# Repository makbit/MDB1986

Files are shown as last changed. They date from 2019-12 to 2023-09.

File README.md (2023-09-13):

## MDB1986 - Milandr Development Board for [K1986BE1QI MCU (package LQFP-144)](https://ic.milandr.ru/products/mikrokontrollery_i_protsessory/32_razryadnye_mikrokontrollery/1986vekh_avia/k1986ve1t/).
> This is an open source hardware project for tutorial purposes.







The PCB was designed in the Eagle CAD 9.0.

The [`Blink103`](Blink103) folder contains firmware for on-board debugger MCU (STM32F103). It can be used to test debugger curcuit and target MCU with JTAG IDCODE instruction. Project files were created with the [Keil uVision MDK](https://www.keil.com/demo/eval/arm.htm). The board schematics can be found in [`MDB1986-Schema.png`](MDB1986-Schema.png) file.

### MDB198 Development Board :cool:
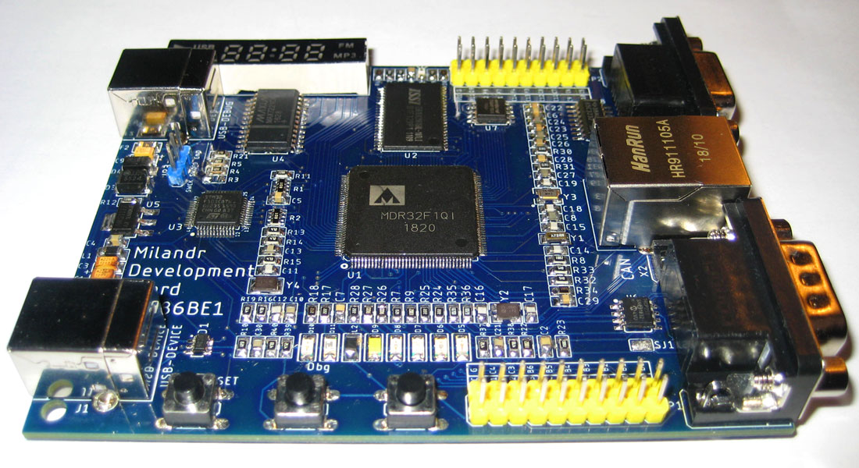
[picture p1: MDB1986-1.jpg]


## TODO :pen:
- [x] Solder the board :+1:
- [x] Download debugger firmware
- [x] Install [MDR Library Pack](https://ic.milandr.ru/soft/)
- [ ] Build and run Demo test
- [ ] Publish articles!

[GitHub readme tips&tricks](https://help.github.com/articles/basic-writing-and-formatting-syntax/)

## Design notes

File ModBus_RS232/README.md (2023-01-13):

## ModBus_RS232 - FreeModBus RTU Slave demonstration firmware for Milandr 1986BE1T (QI) board.
> Platform: Milandr MCU K1986BE1QI.

The source code is based on the [freemodbus library](https://github.com/cwalter-at/freemodbus) by Christian Walter.

### Important note: Add call to "xMBRTUTransmitFSM ();" in mbrtu.c file, Line 215.

This Demo firmware runs at 80MHz and uses UART#2 (Port_D 13, Port_D 14) and Timer #1 with prescaler set to 8.
UART is configured to 115200 baudrate, parity none, 2 stop bits (as recommended by the Standard).
When a button (#1 or #2) is pressed its status is written to the Coils register ucRegCoilsBuf[0], bits 4 and 5.
Color leds can be turned on and off by setting Coils register bits: 0 - blue, 1 - green, 2 - red, 3 - yellow.
Holding registers simply store predefined values: { 0, 1, 2, 3, 4, 5, 6, 7 }.

### Slave address is set to 0x0A (10 decimal).
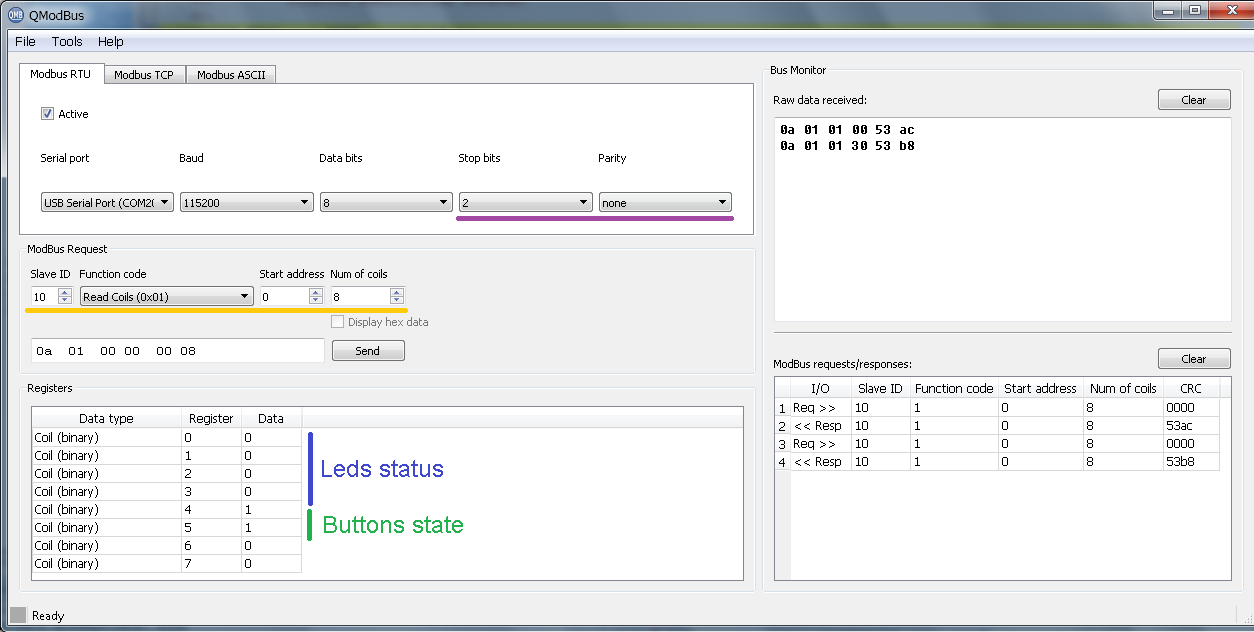
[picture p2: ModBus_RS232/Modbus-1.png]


### Timings
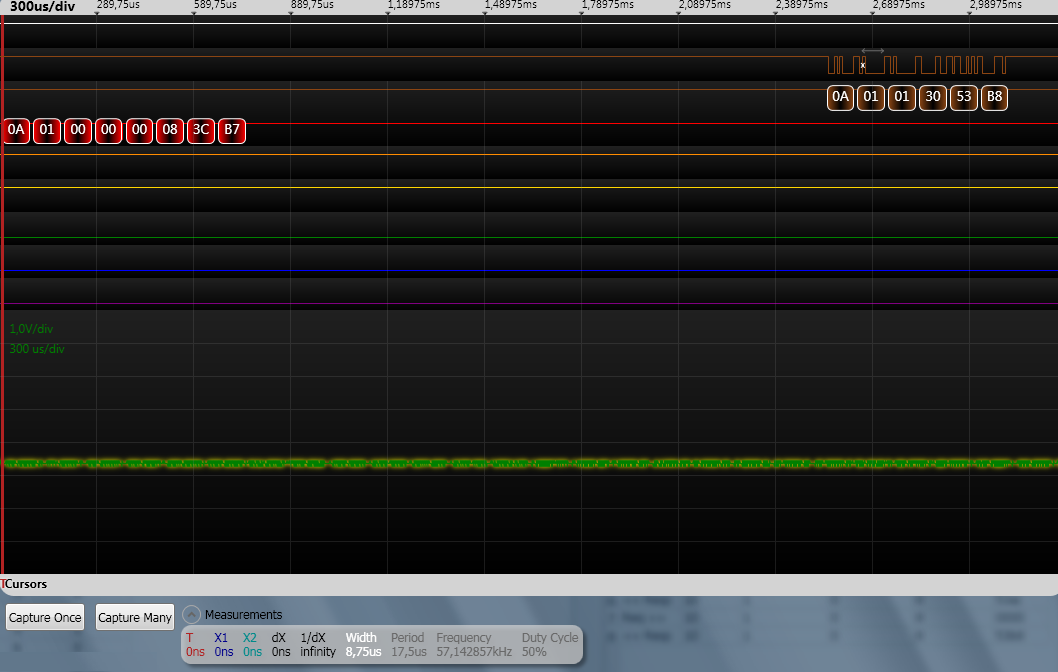
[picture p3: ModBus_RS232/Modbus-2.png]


### Project structure
The project folder contains **modbus** subfolder and the MCU specific **port_1986BE1T**.
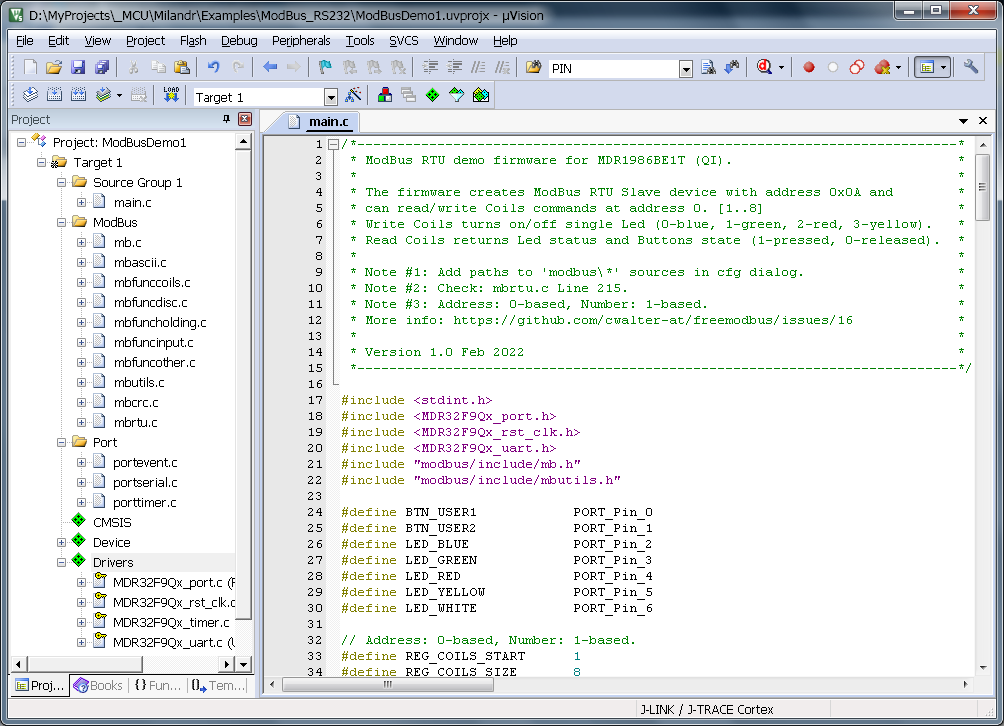
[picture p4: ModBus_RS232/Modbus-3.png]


##### Good luck! 😏

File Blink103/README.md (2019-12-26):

### Blink103 - is a simple firmware for on-board ST-Link debugger for **MDB1986 development board** based on STM32F103 or CS32F103 MCU.
It sends JTAG IDCODE sequence to the main MCU (MDR1986VE1T) and reads the reply. When the reply is a valid Cortex-M IDCODE it flashes the led.

[The Keil uVision 5 IDE](https://keil.com) was used to create and debug this project.
[The SPL (Standard Peripheral Library)](https://www.st.com/en/embedded-software/stsw-stm32054.html) 3.5.0 is required to build this project.
>Connection schematics is similar to any ST-Link clone and can be found in top folder.

### JTAG IDCODE reply on oscilloscope 
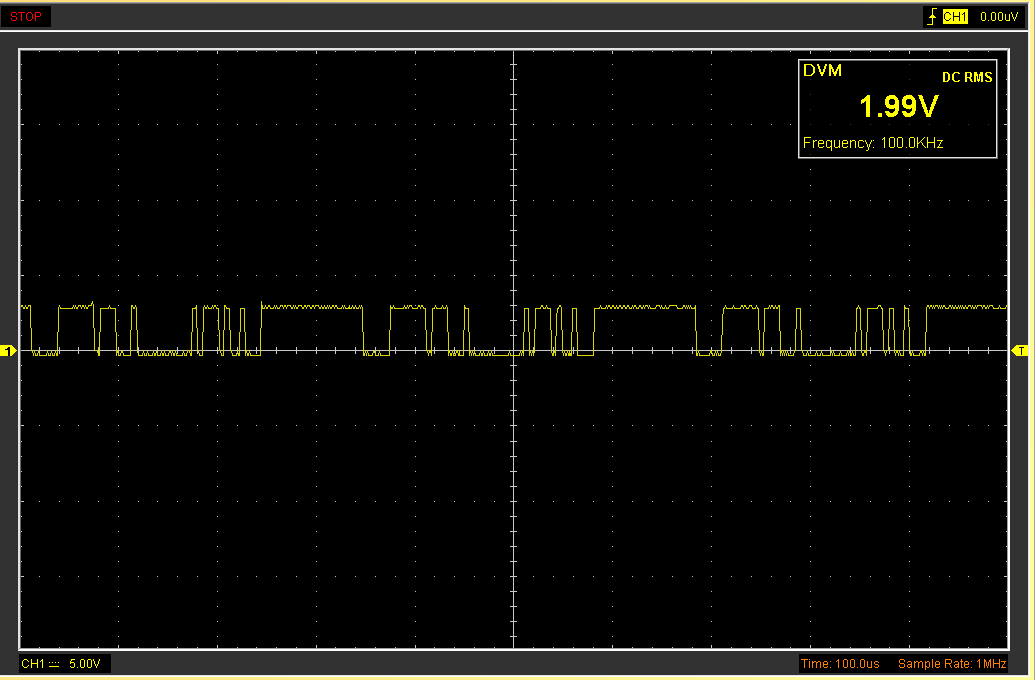
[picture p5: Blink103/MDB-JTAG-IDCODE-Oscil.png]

### Debug session in Keil uVision IDE
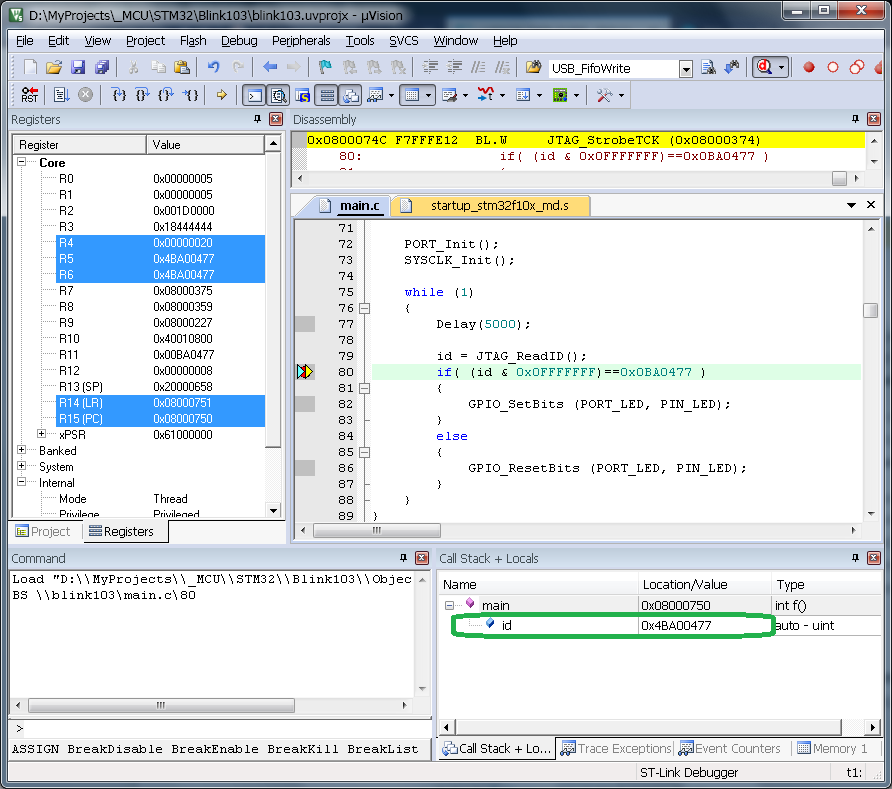
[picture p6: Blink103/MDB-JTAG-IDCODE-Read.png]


:smile:

[GitHub readme tips&tricks](https://help.github.com/articles/basic-writing-and-formatting-syntax/)

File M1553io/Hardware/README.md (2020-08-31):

# M1553io - MIL_STD_1553 input/output shield for MDB1986 Development Board.

This is a simple adapter for connecting the MDB1986 board to the MIL_STD_1553 bus.
It is based on the 5559UH13YA transciever chip by NPO "Physica". This component and transformer can be found in the 5559.lbr file.

##### The adapter board:
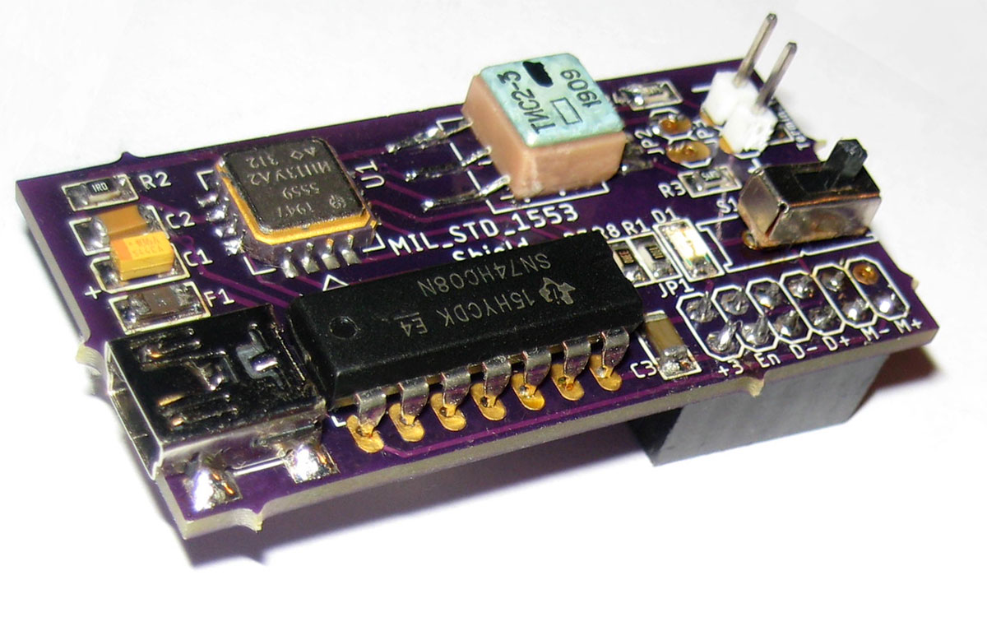
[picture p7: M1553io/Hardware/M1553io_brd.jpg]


##### The adapter schematics:
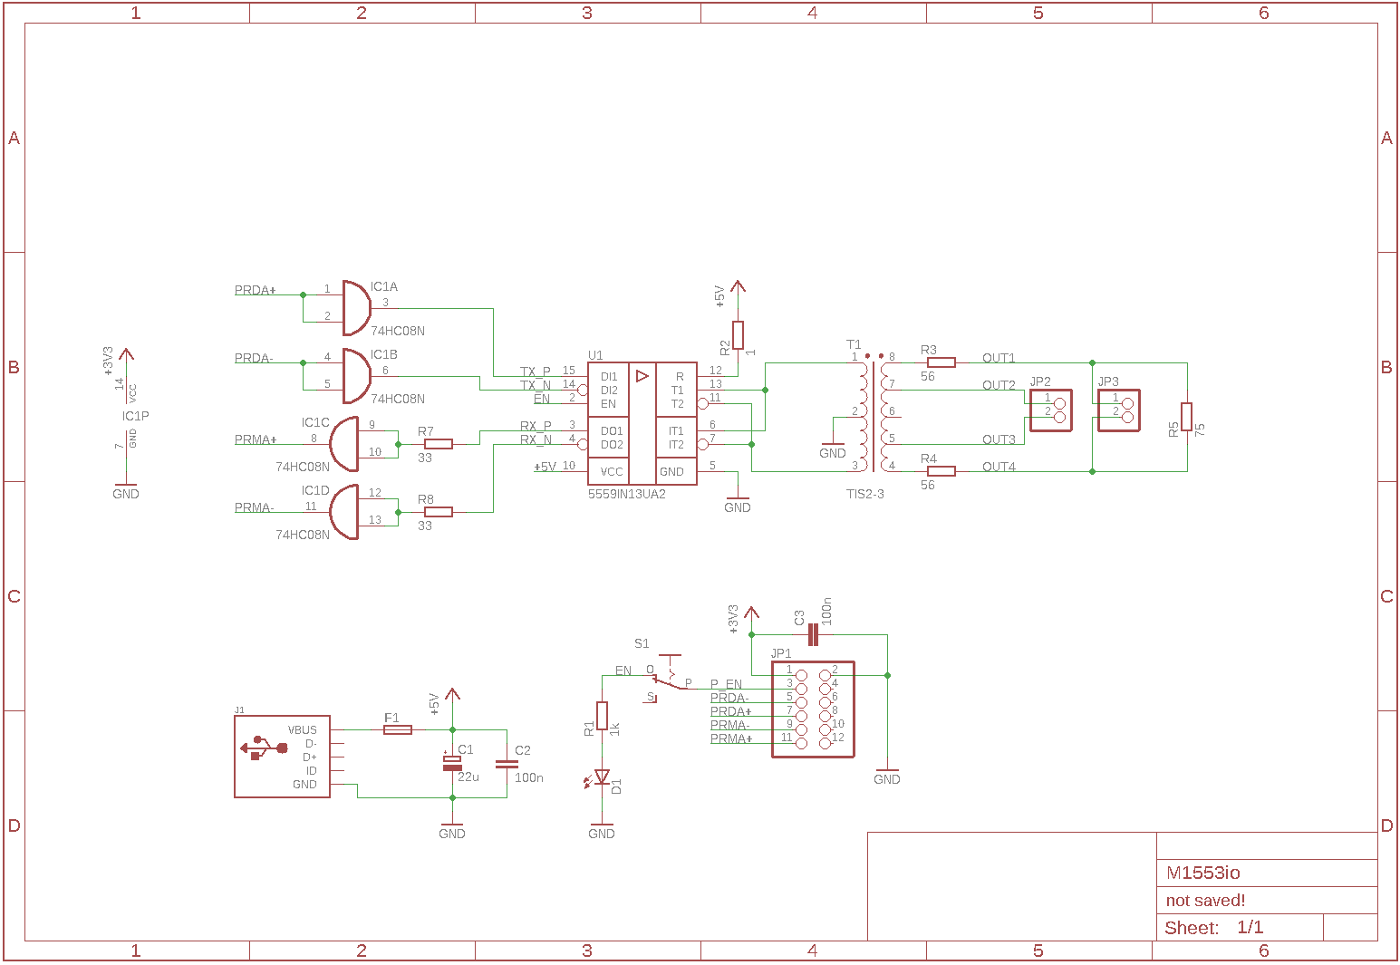
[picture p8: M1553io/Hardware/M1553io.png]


### TODO :pen:
- [ ] Use small package for 74xxx ICC as a level-shifter;
- [ ] P_EN pin should be pulled-down (or up);
- [ ] Check the length of the transformer pins;
- [ ] Add check-points (pin) for Logic-Analyzer;
- [ ] Place all components on the new Development Board;

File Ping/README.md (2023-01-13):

## Ping - ethernet example to test that hardware is functional.
> Platform: Milandr MCU K1986BE1QI.

The source code is based on the SPL example from Milandr software pack.

### Windows ping utility output.
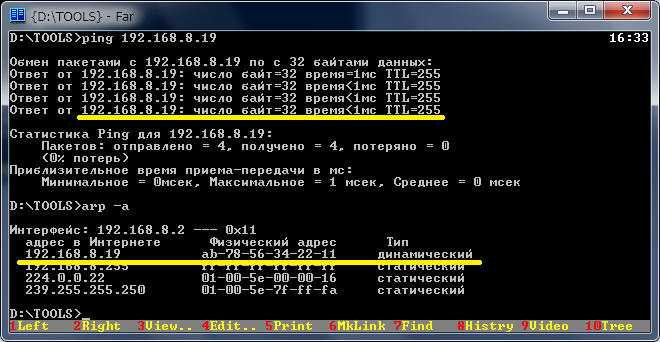
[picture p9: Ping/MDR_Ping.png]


##### Good luck!

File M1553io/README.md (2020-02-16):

## M1553 - MIL_STD_1553 simple input/output demonstration firmware for my MDB1986 board.
> Platform: Milandr MCU K1986BE1QI.

C-style source code (temporary).

### Manchester code of the test I/O sequence on a low-cost Saleae Logic analyzer.
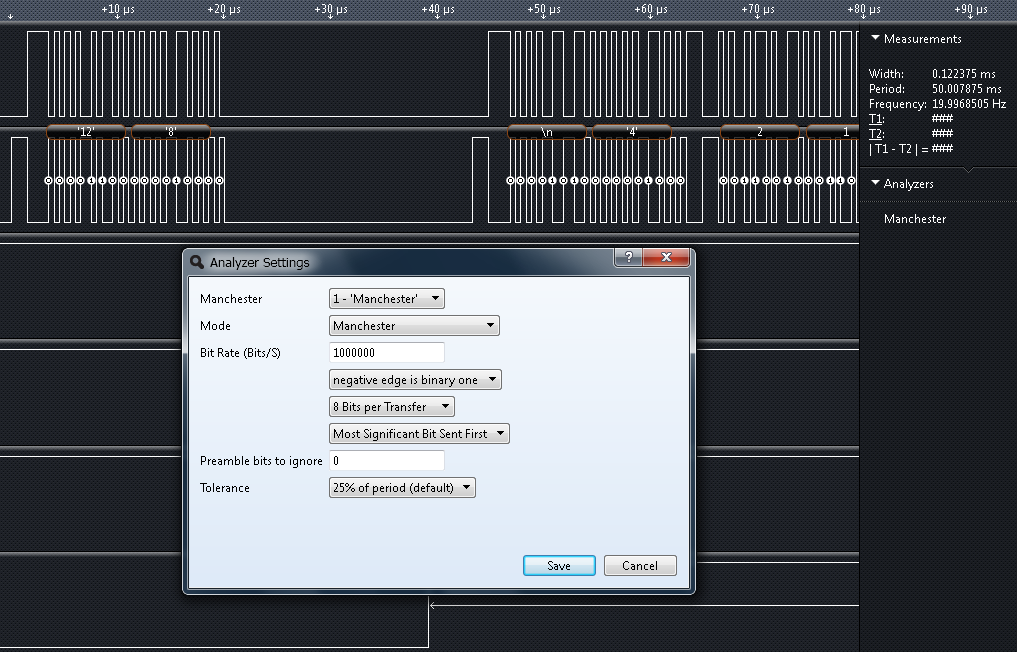
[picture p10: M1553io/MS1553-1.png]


## TODO :pen:
- [x] Logic Analyzer setup & configure
- [x] BC init :+1:
- [x] Flood test sequence
- [ ] Check for status & errors
- [ ] RT init
- [ ] IRQ handler
- [ ] Add required commands
- [ ] Reply StatusWord
- [ ] Send/Recv Vector word
- [ ] Transfer echo/test data
- [ ] Transfer any data
- [ ] Publish articles!

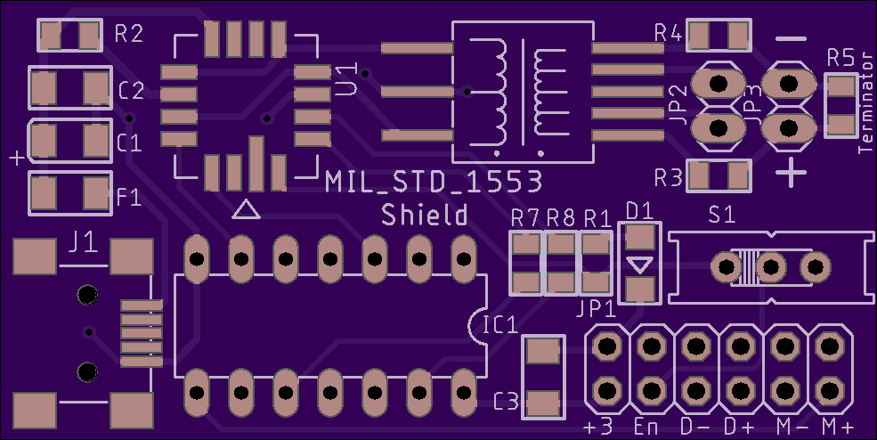
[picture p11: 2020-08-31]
M1553io/Hardware/MS1553Shield-top.png

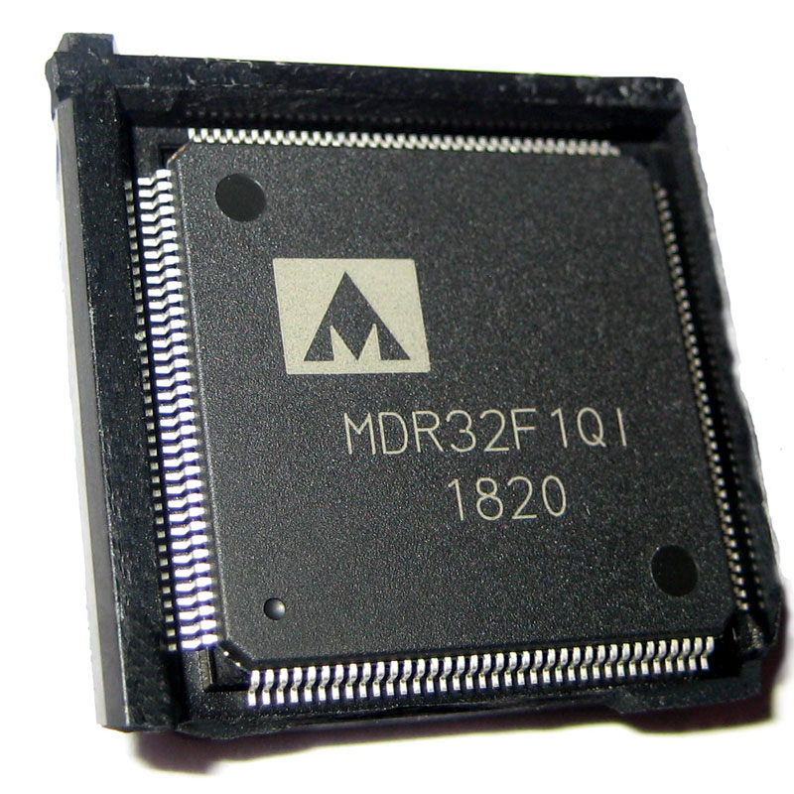
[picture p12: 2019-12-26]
MDR1986-MCU.jpg

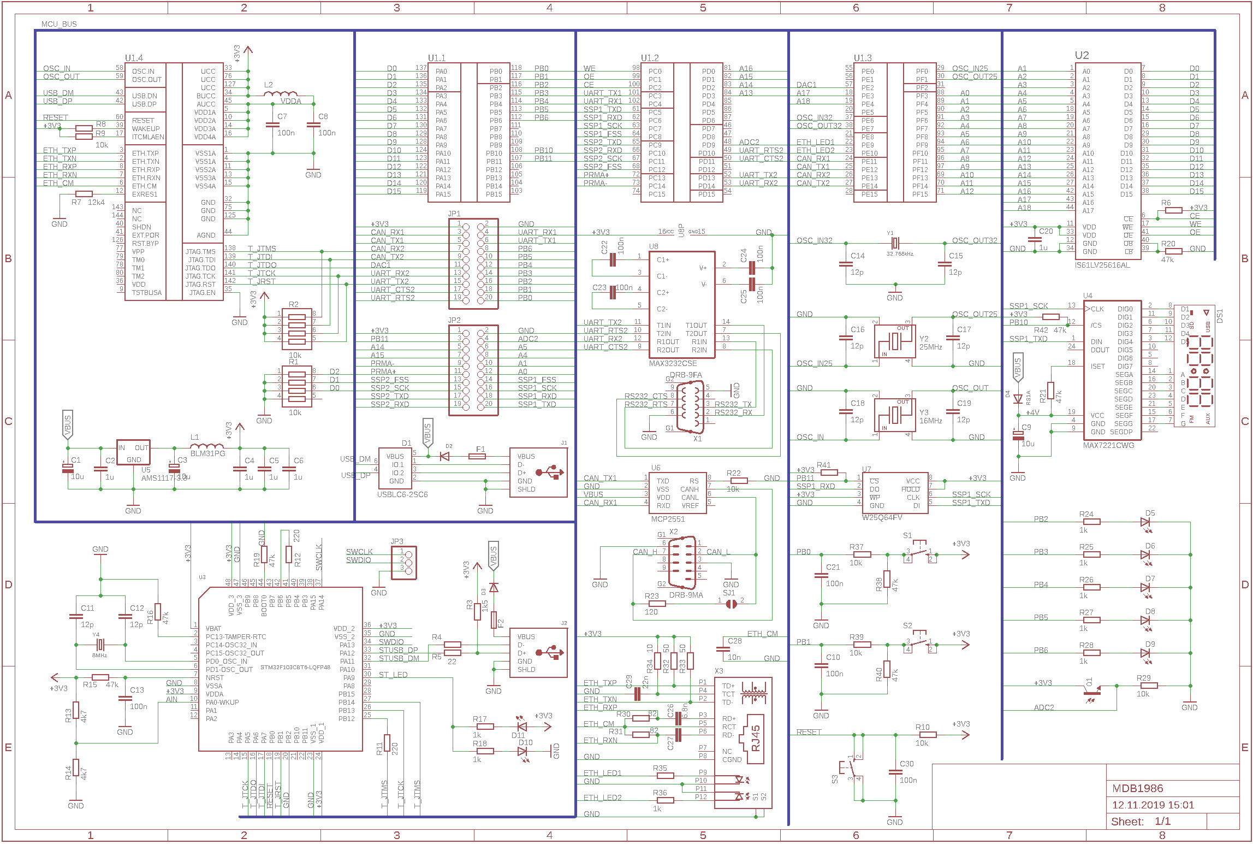
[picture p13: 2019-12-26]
MDB1986-Schema.png

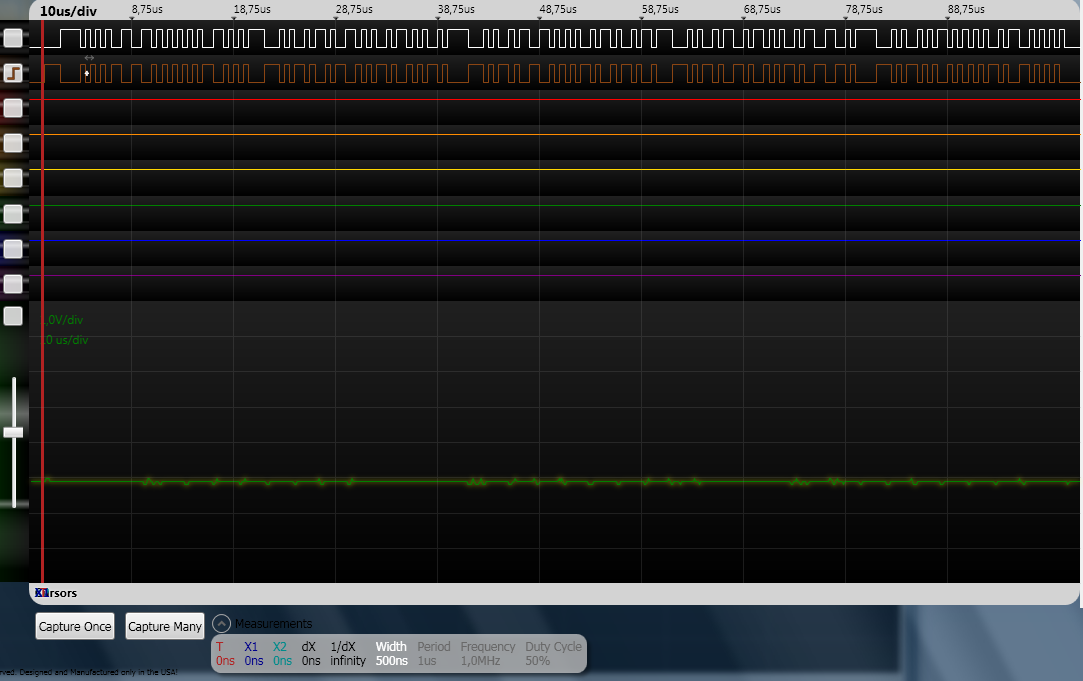
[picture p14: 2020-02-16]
M1553io/MS1553-0.png

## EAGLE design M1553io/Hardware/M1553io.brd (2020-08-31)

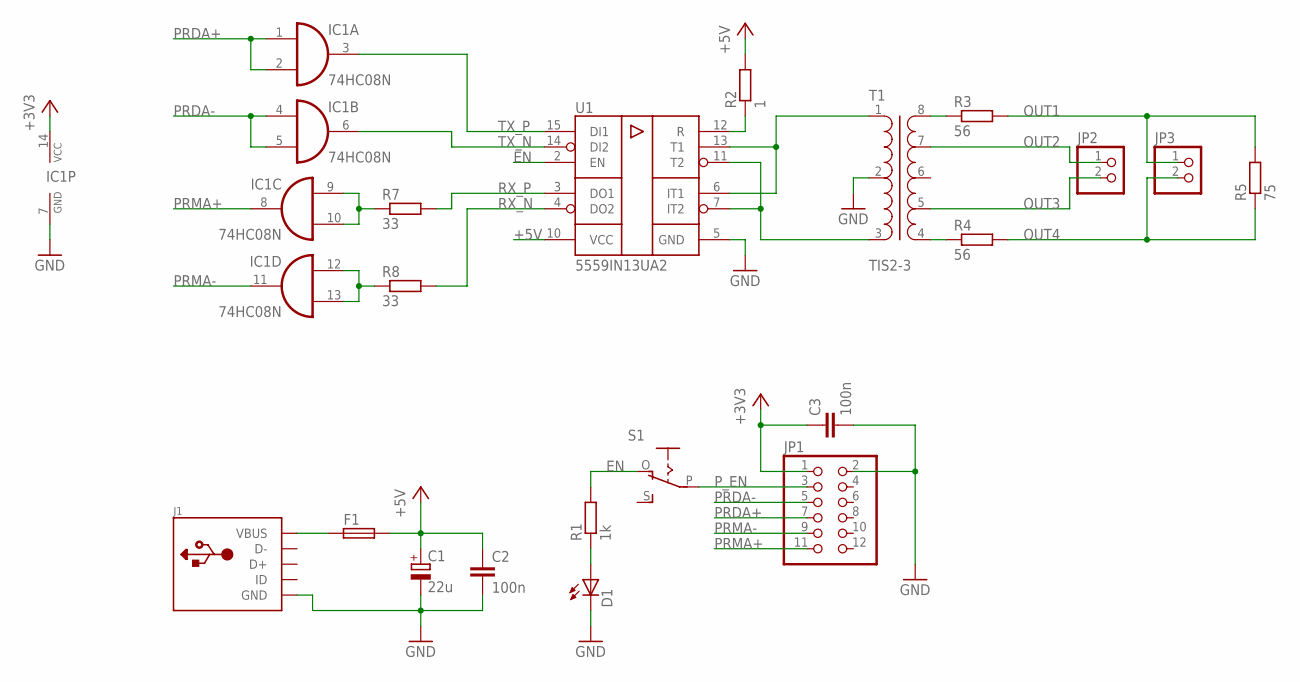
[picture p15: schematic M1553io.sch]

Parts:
C1: 22u; RCL-1206F-POL
C2, C3: 100n; RCL-1206F
D1: LED1206; LED-1206F
F1: FUSE-NSMF; RCL-1206F
IC1: 74HC08N; DIL14
J1: USB-MINI; USB-MINIB
JP1: PINHD-2X6; 2X06
JP2, JP3: PINHD-1X2; 1X02
R1: 1k; RCL-0805F
R2: 1; RCL-0805F
R3, R4: 56; RCL-0805F
R5: 75; RCL-0805F
R7, R8: 33; RCL-0805F
S1: EG1218S; EG1218
T1: TIS2-3
U1: 5559IN13UA2; 5119.16-A

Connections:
+3V3: C3.1, IC1.14 (VCC), JP1.1
+5V: C1.+, C2.1, F1.2, R2.2, U1.10 (VCC)
EN: R1.2, S1.O, U1.2 (EN)
GND: C1.-, C2.2, C3.2, D1.C, IC1.7 (GND), J1.GND, JP1.2, T1.2, U1.5 (GND)
unnamed: R3.1, T1.8
unnamed: R4.1, T1.4
unnamed: R2.1, U1.12 (R)
unnamed: F1.1, J1.VBUS
unnamed: D1.A, R1.1
unnamed: IC1.9 (I0), IC1.10 (I1), R7.1
unnamed: IC1.12 (I0), IC1.13 (I1), R8.1
OUT1: JP3.1, R3.2, R5.2
OUT2: JP2.1, T1.7
OUT3: JP2.2, T1.5
OUT4: JP3.2, R4.2, R5.1
PRDA+: IC1.1 (I0), IC1.2 (I1), JP1.7
PRDA-: IC1.4 (I0), IC1.5 (I1), JP1.5
PRMA+: IC1.8 (O), JP1.11
PRMA-: IC1.11 (O), JP1.9
P_EN: JP1.3, S1.P
RX_N: R8.2, U1.4 (DO2)
RX_P: R7.2, U1.3 (DO1)
T1: T1.1, U1.6 (IT1), U1.13 (T1)
T2: T1.3, U1.7 (IT2), U1.11 (T2)
TX_N: IC1.6 (O), U1.14 (DI2)
TX_P: IC1.3 (O), U1.15 (DI1)

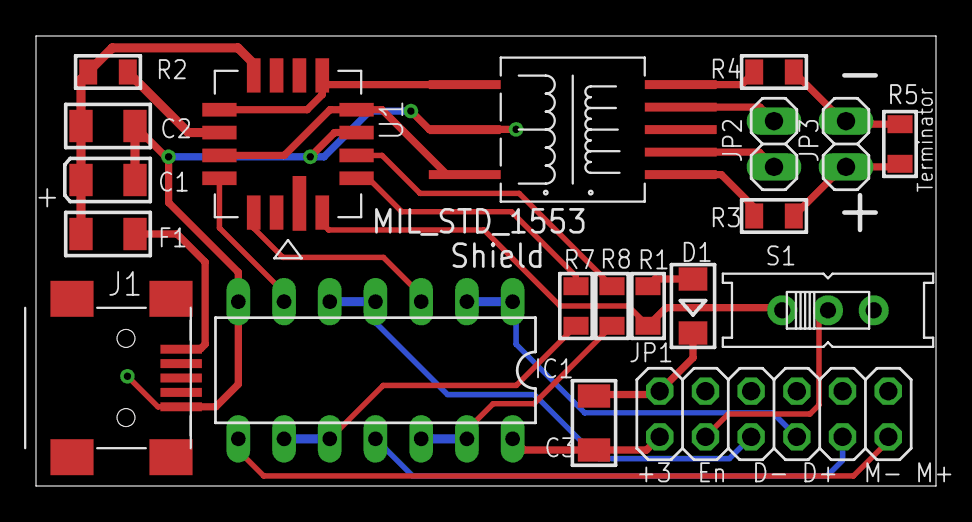
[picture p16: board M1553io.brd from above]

Board: 2 copper layers, 50.0 x 25.0 mm, 20 parts (0 on the bottom side), 26 nets.

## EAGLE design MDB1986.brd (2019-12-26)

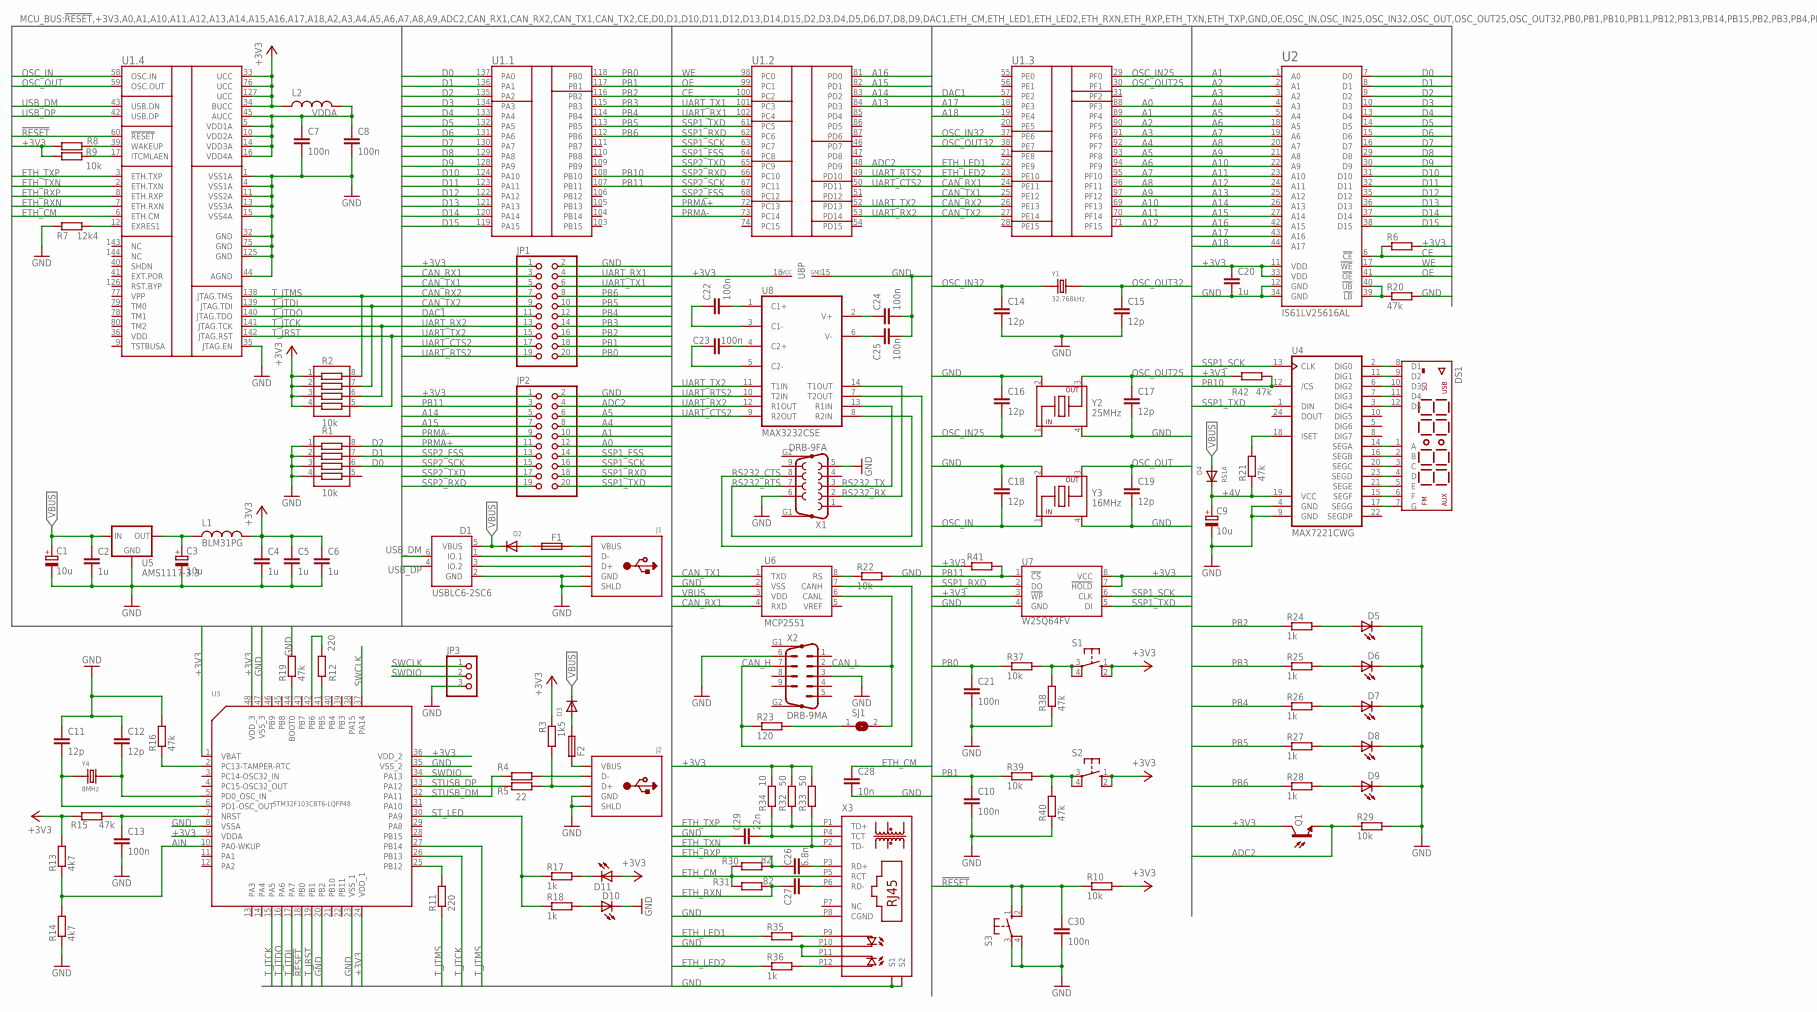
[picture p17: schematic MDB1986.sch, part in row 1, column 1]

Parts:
C1, C3, C9: 10u; RCL-1206F-POL
C2, C4, C5, C6, C20: 1u; RCL-0805F
C7, C8, C10, C13, C21, C22, C23, C24, C25, C30: 100n; RCL-0805F
C11, C12, C14, C15, C16, C17, C18, C19: 12p; RCL-0805F
C26: 6.8n; RCL-0805F
C27: C-EU0805; RCL-0805F
C28: 10n; RCL-0805F
C29: 22n; RCL-0805F
D1: USBLC6-2SC6; SOT-23-6L
D2, D3: DIODEDO-214(SMB); DO-214AA(SMB)
D4: RS1A; DO-214AC(SMA)
D5, D6, D7, D8, D9, D10, D11: LED1206; LED-1206F
DS1: LED-7SEG-12PIN-CC; LED-7SEG-12P2.54
F1, F2: FUSE-NSMF; RCL-1206F
J1, J2: USB-TYPE-B; USB-TYPE-B-4P
JP1, JP2: PINHD-2X10; 2X10
JP3: PINHD-1X3; 1X03
L1: BLM31PG; RCL-1206F
L2: L-EU1206; RCL-1206F
Q1: PHOTOTRANSISTORPT17-21C-L41-TR8; PT17-21C-L41-TR8
R1, R2: 10k; RA-1206-X4
R3: 1k5; RCL-0805F
R4, R6, R8, R35, R41: R-EU0805; RCL-0805F
R5: 22; RCL-0805F
R7: 12k4; RCL-0805F
R9, R10, R22, R29, R37, R39: 10k; RCL-0805F
R11, R12: 220; RCL-0805F
R13, R14: 4k7; RCL-0805F
R15, R16, R19, R20, R21, R38, R40, R42: 47k; RCL-0805F
R17, R18, R24, R25, R26, R27, R28, R36: 1k; RCL-0805F
R23: 120; RCL-0805F
R30, R31: 82; RCL-0805F
R32, R33: 50; RCL-0805F
R34: 10; RCL-0805F
S1, S2, S3: SWITCH-10-XX; BUTTON-B3F-10XX
SJ1: SJ
U1: MCU-K1986BE1QI; LQFP144-0.5-20X20M
U2: IS61LV25616AL; TSOP2-44-400BF
U3: STM32F103CBT6-LQFP48; LQFP48-0.5-7X7MM
U4: MAX7221CWG; SO24W
U5: AMS1117-3.3; SOT223
U6: MCP2551; SO08
U7: W25Q64FV; SOIC-8
U8: MAX3232CSE; SO16
X1: DRB-9FA; F09HP
X2: DRB-9MA; M09HP
X3: HR911105A; RJ45
Y1: 32.768kHz; XTAL-FC-135
Y2: 25MHz; XTAL-FA-238
Y3: 16MHz; XTAL-FA-238
Y4: 8MHz; XTAL-NX3225

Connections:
!RESET: C30.1, R10.1, S3.1 (S), S3.2 (S1), U1.60 (!RESET), U3.18 (PB0)
+3V3: C4.1, C5.1, C6.1, C20.1, D11.A, JP1.1, JP2.1, L1.2, L2.1, Q1.C, R2.1 (P.1), R2.2 (P.2), R2.3 (P.3), R2.4 (P.4), R3.1, R6.2, R8.1, R9.1, R10.2, R13.2, R15.1, R32.2, R33.2, R34.2, R41.1, R42.1, S1.1 (S), S1.2 (S1), S2.1 (S), S2.2 (S1), U1.33 (UCC), U1.34 (BUCC), U1.76 (UCC), U1.127 (UCC), U2.11 (VDD), U2.33 (VDD), U3.1 (VBAT), U3.9 (VDDA), U3.24 (VDD_1), U3.36 (VDD_2), U3.48 (VDD_3), U7.3 (!WP), U7.7 (!HOLD), U7.8 (VCC), U8.16 (VCC)
+4V: C9.+, D4.C, R21.1, U4.19 (VCC)
A0: JP2.12, U1.88 (PF3)
A1: JP2.10, U1.89 (PF4), U2.1 (A0)
A2: U1.90 (PF5), U2.2 (A1)
A3: U1.91 (PF6), U2.3 (A2)
A4: JP2.8, U1.92 (PF7), U2.4 (A3)
A5: JP2.6, U1.93 (PF8), U2.5 (A4)
A6: U1.94 (PF9), U2.18 (A5)
A7: U1.95 (PF10), U2.19 (A6)
A8: U1.96 (PF11), U2.20 (A7)
A9: U1.97 (PF12), U2.21 (A8)
A10: U1.69 (PF13), U2.22 (A9)
A11: U1.70 (PF14), U2.23 (A10)
A12: U1.71 (PF15), U2.24 (A11)
A13: U1.84 (PD3), U2.25 (A12)
A14: JP2.5, U1.83 (PD2), U2.26 (A13)
A15: JP2.7, U1.82 (PD1), U2.27 (A14)
A16: U1.81 (PD0), U2.42 (A15)
A17: U1.18 (PE3), U2.43 (A16)
A18: U1.19 (PE4), U2.44 (A17)
ADC2: JP2.4, Q1.E, R29.1, U1.48 (PD9)
AIN: R13.1, R14.2, U3.10 (PA0-WKUP)
BOOT0: R19.1, U3.44 (BOOT0)
CAN_H: R23.1, U6.7 (CANH), X2.7
CAN_L: SJ1.2, U6.6 (CANL), X2.2
CAN_RX1: JP1.3, U1.24 (PE11), U6.4 (RXD)
CAN_RX2: JP1.7, U1.26 (PE13)
CAN_TX1: JP1.5, U1.25 (PE12), U6.1 (TXD)
CAN_TX2: JP1.9, U1.27 (PE14)
CE: R6.1, U1.100 (PC2), U2.6 (!CE)
D0: R1.6 (P.6), U1.137 (PA0), U2.7 (D0)
D1: R1.7 (P.7), U1.136 (PA1), U2.8 (D1)
D2: R1.8 (P.8), U1.135 (PA2), U2.9 (D2)
D3: U1.134 (PA3), U2.10 (D3)
D4: U1.133 (PA4), U2.13 (D4)
D5: U1.132 (PA5), U2.14 (D5)
D6: U1.131 (PA6), U2.15 (D6)
D7: U1.130 (PA7), U2.16 (D7)
D8: U1.129 (PA8), U2.29 (D8)
D9: U1.128 (PA9), U2.30 (D9)
D10: U1.124 (PA10), U2.31 (D10)
D11: U1.123 (PA11), U2.32 (D11)
D12: U1.122 (PA12), U2.35 (D12)
D13: U1.121 (PA13), U2.36 (D13)
D14: U1.120 (PA14), U2.37 (D14)
D15: U1.119 (PA15), U2.38 (D15)
DAC1: JP1.11, U1.57 (PE2)
ETH_CM: C28.1, R30.1, R31.1, U1.6 (ETH.CM), X3.P5 (RCT)
ETH_LED1: R35.1, U1.22 (PE9)
ETH_LED2: R36.1, U1.23 (PE10)
ETH_RXN: C27.1, R31.2, U1.7 (ETH.RXN)
ETH_RXP: C26.1, R30.2, U1.8 (ETH.RXP)
ETH_TXN: R33.1, U1.2 (ETH.TXN), X3.P2 (TD-)
ETH_TXP: R32.1, U1.3 (ETH.TXP), X3.P1 (TD+)
GND: C1.-, C2.2, C3.-, C4.2, C5.2, C6.2, C7.2, C8.2, C9.-, C10.2, C11.1, C12.1, C13.2, C14.2, C15.2, C16.1, C17.2, C18.1, C19.2, C20.2, C21.2, C24.2, C25.2, C28.2, C29.1, C30.2, D1.2 (GND), D5.C, D6.C, D7.C, D8.C, D9.C, D10.C, J1.4_GND (GND), J1.M1 (SHLD), J1.M2 (SHLD), J2.4_GND (GND), J2.M1 (SHLD), J2.M2 (SHLD), JP1.2, JP2.2, JP3.3, R1.1 (P.1), R1.2 (P.2), R1.3 (P.3), R1.4 (P.4), R7.1, R14.1, R16.2, R19.2, R20.2, R22.2, R29.2, R38.1, R40.1, S3.3, S3.4 (P1), U1.1 (VSS1A), U1.4 (VSS1A), U1.11 (VSS2A), U1.13 (VSS3A), U1.15 (VSS4A), U1.32 (GND), U1.35 (JTAG.EN), U1.44 (AGND), U1.75 (GND), U1.125 (GND), U2.12 (GND), U2.34 (GND), U3.8 (VSSA), U3.20 (PB2), U3.23 (VSS_1), U3.35 (VSS_2), U3.47 (VSS_3), U4.4 (GND), U4.9 (GND), U5.1 (GND), U6.2 (VSS), U7.4 (GND), U8.15 (GND), X1.5, X1.6, X2.3, X2.6, X3.P8 (CGND), X3.P10 (GLED-), X3.P11 (YLED-), X3.SHIELD1 (S1), X3.SHIELD2 (S2), Y2.2, Y2.4, Y3.2, Y3.4
unnamed: DS1.8 (D1), U4.2 (DIG0)
unnamed: DS1.9 (D2), U4.11 (DIG1)
unnamed: DS1.10 (D3), U4.6 (DIG2)
unnamed: DS1.11 (D4), U4.7 (DIG3)
unnamed: DS1.12 (D5), U4.3 (DIG4)
unnamed: DS1.1 (A), U4.14 (SEGA)
unnamed: DS1.2 (B), U4.16 (SEGB)
unnamed: DS1.3 (C), U4.20 (SEGC)
unnamed: DS1.4 (D), U4.23 (SEGD)
unnamed: DS1.5 (E), U4.21 (SEGE)
unnamed: DS1.6 (F), U4.15 (SEGF)
unnamed: DS1.7 (G), U4.17 (SEGG)
unnamed: F1.1, J1.1_VBUS (VBUS)
unnamed: D2.A, F1.2
unnamed: C12.2, U3.5 (PD0_OSC_IN), Y4.2
unnamed: C11.2, U3.6 (PD1-OSC_OUT), Y4.1
unnamed: R21.2, U4.18 (ISET)
unnamed: D10.A, R18.2
unnamed: R12.1, U3.41 (PB5)
unnamed: R12.2, U3.42 (PB6)
unnamed: C3.+, L1.1, U5.2 (OUT), U5.4 (OUT)
unnamed: R11.2, U3.25 (PB12)
unnamed: D11.C, R17.2
unnamed: J2.2_DM (D-), R4.1
unnamed: J2.3_DP (D+), R3.2, R5.1
unnamed: C22.2, U8.1 (C1+)
unnamed: F2.1, J2.1_VBUS (VBUS)
unnamed: C13.1, R15.2, U3.7 (NRST)
unnamed: R8.2, U1.39 (WAKEUP)
unnamed: R9.2, U1.17 (ITCMLAEN)
unnamed: C22.1, U8.3 (C1-)
unnamed: R16.1, U3.2 (PC13-TAMPER-RTC)
unnamed: C23.2, U8.4 (C2+)
unnamed: C23.1, U8.5 (C2-)
unnamed: C25.1, U8.6 (V-)
unnamed: C24.1, U8.2 (V+)
unnamed: R20.1, U2.39 (!LB), U2.40 (!UB)
unnamed: R7.2, U1.12 (EXRES1)
unnamed: R23.2, SJ1.1
unnamed: R22.1, U6.8 (RS)
unnamed: D3.A, F2.2
unnamed: D9.A, R28.2
unnamed: D8.A, R27.2
unnamed: D7.A, R26.2
unnamed: R37.2, R38.2, S1.3, S1.4 (P1)
unnamed: D6.A, R25.2
unnamed: D5.A, R24.2
unnamed: C29.2, R34.1, X3.P4 (TCT)
unnamed: R36.2, X3.P12 (YLED+)
unnamed: R35.2, X3.P9 (GLED+)
unnamed: C27.2, X3.P6 (RD-)
unnamed: C26.2, X3.P3 (RD+)
unnamed: R39.2, R40.2, S2.3, S2.4 (P1)
OE: U1.99 (PC1), U2.41 (!OE)
OSC_IN: C18.2, U1.58 (OSC.IN), Y3.1 (X.IN)
OSC_IN25: C16.2, U1.29 (PF0), Y2.1 (X.IN)
OSC_IN32: C14.1, U1.37 (PE6), Y1.1
OSC_OUT: C19.1, U1.59 (OSC.OUT), Y3.3 (X.OUT)
OSC_OUT25: C17.1, U1.30 (PF1), Y2.3 (X.OUT)
OSC_OUT32: C15.1, U1.38 (PE7), Y1.2
PB0: C21.1, JP1.20, R37.1, U1.118 (PB0)
PB1: C10.1, JP1.18, R39.1, U1.117 (PB1)
PB2: JP1.16, R24.1, U1.116 (PB2)
PB3: JP1.14, R25.1, U1.115 (PB3)
PB4: JP1.12, R26.1, U1.114 (PB4)
PB5: JP1.10, R27.1, U1.113 (PB5)
PB6: JP1.8, R28.1, U1.112 (PB6)
PB10: R42.2, U1.108 (PB10), U4.12 (/CS)
PB11: JP2.3, R41.2, U1.107 (PB11), U7.1 (!CS)
PRMA+: JP2.11, U1.72 (PC13)
PRMA-: JP2.9, U1.73 (PC14)
RS232_CTS: U8.7 (T2OUT), X1.8
RS232_RTS: U8.8 (R2IN), X1.7
RS232_RX: U8.14 (T1OUT), X1.2
RS232_TX: U8.13 (R1IN), X1.3
SSP1_FSS: JP2.14, U1.64 (PC8)
SSP1_RXD: JP2.18, U1.62 (PC6), U7.2 (DO)
SSP1_SCK: JP2.16, U1.63 (PC7), U4.13 (CLK), U7.6 (CLK)
SSP1_TXD: JP2.20, U1.61 (PC5), U4.1 (DIN), U7.5 (DI)
SSP2_FSS: JP2.13, U1.68 (PC12)
SSP2_RXD: JP2.19, U1.66 (PC10)
SSP2_SCK: JP2.15, U1.67 (PC11)
SSP2_TXD: JP2.17, U1.65 (PC9)
STUSB_DM: R4.2, U3.32 (PA11)
STUSB_DP: R5.2, U3.33 (PA12)
ST_LED: R17.1, R18.1, U3.30 (PA9)
SWCLK: JP3.1, U3.37 (PA14)
SWDIO: JP3.2, U3.34 (PA13)
T_JRST: R2.5 (P.5), U1.142 (JTAG.RST), U3.19 (PB1)
T_JTCK: R2.6 (P.6), U1.141 (JTAG.TCK), U3.15 (PA5), U3.26 (PB13)
T_JTDI: R2.7 (P.7), U1.139 (JTAG.TDI), U3.17 (PA7)
T_JTDO: U1.140 (JTAG.TDO), U3.16 (PA6)
T_JTMS: R2.8 (P.8), R11.1, U1.138 (JTAG.TMS), U3.27 (PB14)
UART_CTS2: JP1.17, U1.50 (PD11), U8.9 (R2OUT)
UART_RTS2: JP1.19, U1.49 (PD10), U8.10 (T2IN)
UART_RX1: JP1.4, U1.102 (PC4)
UART_RX2: JP1.13, U1.53 (PD14), U8.12 (R1OUT)
UART_TX1: JP1.6, U1.101 (PC3)
UART_TX2: JP1.15, U1.52 (PD13), U8.11 (T1IN)
USB_D+: D1.3 (IO.2), J1.3_DP (D+)
USB_D-: D1.1 (IO.1), J1.2_DM (D-)
USB_DM: D1.6 (IO_1), U1.43 (USB.DN)
USB_DP: D1.4 (IO_2), U1.42 (USB.DP)
VBUS: C1.+, C2.1, D1.5 (VBUS), D2.C, D3.C, D4.A, U5.3 (IN), U6.3 (VDD)
VDDA: C7.1, C8.1, L2.2, U1.5 (VDD1A), U1.10 (VDD2A), U1.14 (VDD3A), U1.16 (VDD4A), U1.45 (AUCC)
WE: U1.98 (PC0), U2.17 (!WE)

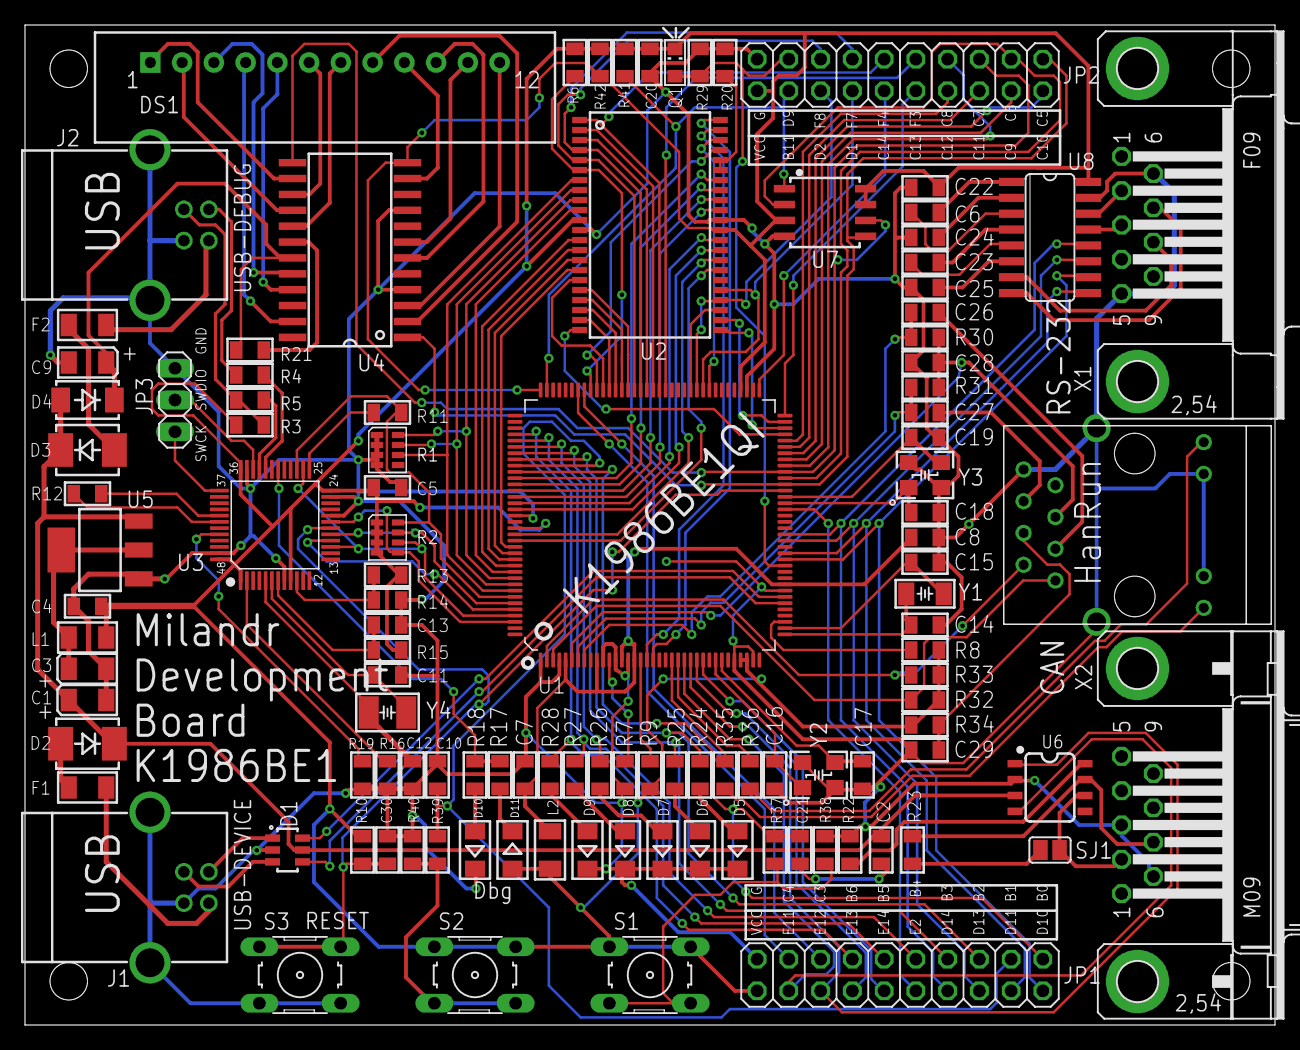
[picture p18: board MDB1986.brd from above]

Board: 2 copper layers, 100.0 x 80.0 mm, 113 parts (0 on the bottom side), 163 nets.

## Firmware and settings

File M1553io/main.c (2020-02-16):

/*---------------------------------------------------------------------------*
 * Project:  MIL_STD_1553B simple input/output demonstration firmware.       *
 * Info:     C-style initialization of the BusController and                 *
 *           transfer of 4 words ("12 34 56 78") to RT with TDA = 1.         *
 * Platform: Milandr 1986VE1T (plasic QFP-144)                               *
 * File:     M1553io/main.c                                                  *
 * Version:  0.1 Feb 2020                                                    *
 * Author:   MKM                                                             *
 *---------------------------------------------------------------------------*/
#include <stdint.h>
#include <MDR32F9Qx_port.h>
#include <MDR32F9Qx_rst_clk.h>
#include <MDR32F9Qx_timer.h>
#include <MDR32F9Qx_rst_clk.h>
#include <MDR32F9Qx_eeprom.h>
#include <MDR32F9Qx_mil_std_1553.h>
#include "ms1553.h"

// PortB
#define MDB_LED_BLUE                   PORT_Pin_2
#define MDB_LED_GREEN                  PORT_Pin_3
#define MDB_LED_RED                    PORT_Pin_4
#define MDB_LED_YELLOW                 PORT_Pin_5
#define MDB_LED_WHITE                  PORT_Pin_6
#define MDB_MAX7221_CS                 PORT_Pin_10
#define MDB_FLASH_CS                   PORT_Pin_11

// 1ms time counter
//extern 
uint32_t g_msTickCount;

extern void LED_Init (void);
extern void SYSCLK_Init (void);
extern void TIMER1_Init (void);
extern void MS1553_Init_BC (void);
extern void MS1553_Init_RT (void);

extern int  MS1553_Wait (uint32_t flag);
extern int  MS1553_Cmd  (uint8_t tda, uint8_t cmd);
extern int  MS1553_Send (uint8_t tda, uint8_t sub, uint8_t nWords, void *pData);
//extern int  MS1553_Recv (uint8_t tda, uint8_t sub, uint8_t nWords, void *pData);

//===========================================================================//
void DelayMS(uint32_t ms)
{
	uint32_t tick = g_msTickCount;
	while( tick + ms > g_msTickCount ) ;
}

//===========================================================================//
int main()
{
	LED_Init();
	SYSCLK_Init();
	TIMER1_Init();
	MS1553_Init_BC();

	// MS1553_Init_RT(adr);

	while(1)
	{
		PORT_ResetBits (MDR_PORTB, MDB_LED_GREEN);
		PORT_ResetBits (MDR_PORTB, MDB_LED_RED);

		PORT_SetBits (MDR_PORTB, MDB_FLASH_CS);
		MS1553_Send (1, 16, 4, "12345678");
		MS1553_Wait (MIL_STD_1553_FLAG_IDLE);
		PORT_ResetBits (MDR_PORTB, MDB_FLASH_CS);

		if( MIL_STD_1553_GetFlagStatus(MDR_MIL_STD_15531, MIL_STD_1553_FLAG_ERR)==SET )
		{
			volatile uint32_t e;
			PORT_SetBits (MDR_PORTB, MDB_LED_RED);

			e = MIL_STD_1553_GetErrorStatus(MDR_MIL_STD_15531);
			if( e ) PORT_SetBits (MDR_PORTB, MDB_LED_BLUE);
			PORT_ResetBits (MDR_PORTB, MDB_LED_BLUE);
		}
		else
		{
			PORT_SetBits (MDR_PORTB, MDB_LED_GREEN);
		}
		DelayMS(100);

		MS1553_Cmd (1, MS1553_CMD_RESET);
		//MS1553_Cmd (1, MS1553_CMD_STATUS_WORD);
		MS1553_Wait (MIL_STD_1553_FLAG_IDLE);
	}
}

//===========================================================================//
// Configure PORTB pins for LED on/off                                       //
//===========================================================================//
void LED_Init ( void )
{
	PORT_InitTypeDef PORT_InitStruct;

	PORT_StructInit (&PORT_InitStruct);
	RST_CLK_PCLKcmd (RST_CLK_PCLK_PORTB, ENABLE);

	PORT_InitStruct.PORT_FUNC  = PORT_FUNC_PORT;
	PORT_InitStruct.PORT_OE    = PORT_OE_OUT;
	PORT_InitStruct.PORT_MODE  = PORT_MODE_DIGITAL;
	PORT_InitStruct.PORT_SPEED = PORT_SPEED_FAST;
	PORT_InitStruct.PORT_Pin   = MDB_LED_BLUE | MDB_LED_GREEN |
	                             MDB_LED_YELLOW | MDB_LED_RED |
	                             MDB_MAX7221_CS | MDB_FLASH_CS;
	PORT_Init (MDR_PORTB, &PORT_InitStruct);
}

//===========================================================================//
// 80 MHz, HSEdiv1, PLLmul5                                                  //
//===========================================================================//
void SYSCLK_Init ( void )
{
	// Configure FLASH access time for speed >120MHz
	RST_CLK_PCLKcmd (RST_CLK_PCLK_EEPROM, ENABLE);
	//--------------------------------//
	// MCU Frequency | Flash Latency  //
	//---------------|----------------//
	//   <  25 MHz   |    0           //
	//   <  50 MHz   |    1           //
	//   <  75 MHz   |    2           //
	//   < 100 MHz   |    3           //
	//   < 125 MHz   |    4 (default) //
	//   < 150 MHz   |    5           //
	//   < 175 MHz   |    6           //
	//--------------------------------//
	EEPROM_SetLatency (EEPROM_Latency_3);

	// HSE on
	RST_CLK_HSEconfig (RST_CLK_HSE_ON);
	while( RST_CLK_HSEstatus() != SUCCESS ) ;

	// CPU_C1_SEL = HSE, 16 x 5 = 80MHz
	RST_CLK_CPU_PLLconfig ( RST_CLK_CPU_PLLsrcHSEdiv1, RST_CLK_CPU_PLLmul5 ); // 80MHz
	RST_CLK_CPU_PLLcmd (ENABLE);
	while( RST_CLK_CPU_PLLstatus() != SUCCESS ) ;

	// CPU_C3_SEL = CPU_C2_SEL
	RST_CLK_CPUclkPrescaler (RST_CLK_CPUclkDIV1);
	// CPU_C2_SEL = PLL
	RST_CLK_CPU_PLLuse (ENABLE);
	// HCLK_SEL = CPU_C3_SEL
	RST_CLK_CPUclkSelection (RST_CLK_CPUclkCPU_C3);
}

//===========================================================================//
// Timer #1 @ 1000us (1ms)                                                   //
//===========================================================================//
void TIMER1_Init (void)
{
	TIMER_CntInitTypeDef timer = { 0 };
	RST_CLK_FreqTypeDef  freq  = { 0 };

	RST_CLK_PCLKcmd (RST_CLK_PCLK_TIMER1, ENABLE);

	TIMER_DeInit (MDR_TIMER1);
	TIMER_CntStructInit (&timer);
	TIMER_BRGInit (MDR_TIMER1, TIMER_HCLKdiv1);
	RST_CLK_GetClocksFreq (&freq);

	timer.TIMER_CounterMode = TIMER_CntMode_ClkFixedDir;
	timer.TIMER_Period      = freq.CPU_CLK_Frequency/1000000 * 1000; // 1000us
	TIMER_CntInit (MDR_TIMER1, &timer);
	TIMER_ITConfig (MDR_TIMER1, TIMER_STATUS_CNT_ARR, ENABLE);

	NVIC_EnableIRQ(TIMER1_IRQn);
	TIMER_Cmd(MDR_TIMER1, ENABLE);
}

//===========================================================================//
void TIMER1_IRQHandler(void)
{
	TIMER_ClearITPendingBit (MDR_TIMER1, TIMER_STATUS_CNT_ARR);
	g_msTickCount++;
}

//===========================================================================//
// MS1553_Init() - initializes MIL_STD_1553 Bus Controller                   //
//===========================================================================//
void MS1553_Init_BC (void)
{
	PORT_InitTypeDef         PORT_InitStruct      = { 0 };
	MIL_STD_1553_InitTypeDef MS1553_InitStructure = { 0 };

	RST_CLK_PCLKcmd (RST_CLK_PCLK_MIL_STD_15531, ENABLE);
	RST_CLK_PCLKcmd (RST_CLK_PCLK_PORTC, ENABLE);
	RST_CLK_PCLKcmd (RST_CLK_PCLK_PORTD, ENABLE);	
	
	PORT_StructInit (&PORT_InitStruct);

	// PRMA+/-: PortC #13,14(,15)
	PORT_InitStruct.PORT_Pin   = PORT_Pin_13 | PORT_Pin_14;// | PORT_Pin_15;
	PORT_InitStruct.PORT_FUNC  = PORT_FUNC_MAIN;
	PORT_InitStruct.PORT_SPEED = PORT_SPEED_FAST;
	PORT_InitStruct.PORT_MODE  = PORT_MODE_DIGITAL;
	PORT_Init (MDR_PORTC, &PORT_InitStruct);

	// PRMD+/-: PortD #1,2,(5)
	PORT_InitStruct.PORT_Pin   = PORT_Pin_1 | PORT_Pin_2;// | PORT_Pin_5;
	PORT_InitStruct.PORT_FUNC  = PORT_FUNC_MAIN;
	PORT_InitStruct.PORT_SPEED = PORT_SPEED_FAST;
	PORT_InitStruct.PORT_MODE  = PORT_MODE_DIGITAL;
	PORT_Init (MDR_PORTD, &PORT_InitStruct);

	// Reset all MIL_STD_15531 settings
	MIL_STD_1553_DeInit (MDR_MIL_STD_15531);
	MIL_STD_1553_BRGInit (MIL_STD_1553_HCLKdiv1);
	MIL_STD_1553xStructInit (&MS1553_InitStructure);

	// Initialize MIL_STD_1553_InitStructure
	MS1553_InitStructure.MIL_STD_1553_Mode = MIL_STD_1553_ModeBusController;
	MS1553_InitStructure.MIL_STD_1553_RERR = DISABLE; // auto reset errors 
	MS1553_InitStructure.MIL_STD_1553_DIV  = 80;      // 80Mhz/80 = 1Mhz
	MS1553_InitStructure.MIL_STD_1553_RTA  = 0;       // not used for BC
	MS1553_InitStructure.MIL_STD_1553_TRA  = ENABLE;  // use main channel A
	MS1553_InitStructure.MIL_STD_1553_TRB  = DISABLE; // channel B reserved

	// Configure MIL_STD_15531 parameters
	MIL_STD_1553_Init (MDR_MIL_STD_15531, &MS1553_InitStructure);
	MIL_STD_1553_Cmd (MDR_MIL_STD_15531, ENABLE);
}

//===========================================================================//
// MS1553_Wait() - waits for MIL_STD_1553 event/status                       //
//===========================================================================//
int MS1553_Wait (uint32_t flag)
{
	uint32_t tick = g_msTickCount + 2;
	assert_param( IS_MIL_STD_1553_FLAG(flag) );
	while( MIL_STD_1553_GetFlagStatus(MDR_MIL_STD_15531, flag) != SET )
	{
		if( tick==g_msTickCount ) return ERROR;
	}
	return SUCCESS;
}

//===========================================================================//
// MS1553_Cmd() - issues command to TD                                       //
//===========================================================================//
int MS1553_Cmd  (uint8_t tda, uint8_t cmd)
{
	MIL_STD_1553_CommandWordTypeDef command;

	assert_param( tda < 32);
	assert_param( cmd <= MS1553_CMD_OVERRIDE_STX );

	command.CommandWord                  = 0;
	command.Fields.ReadWriteBit          = MIL_STD_1553_TD_TO_BC;
	command.Fields.Data                  = cmd;
	command.Fields.Subaddress            = 0;
	command.Fields.TerminalDeviceAddress = tda;
	if( cmd==MS1553_CMD_SYNC_WITH_DATA || cmd==MS1553_CMD_SHUTDOWN_SEL || cmd==MS1553_CMD_OVERRIDE_SEL )
	{
		command.Fields.ReadWriteBit      = MIL_STD_1553_BC_TO_TD;
	}

	MDR_MIL_STD_15531->CommandWord1 = command.CommandWord;
	MIL_STD_1553_StartTransmision (MDR_MIL_STD_15531);
	return SUCCESS;
}

//===========================================================================//
// MS1553_Send() - sends pData to the 1553 bus (format #1)                   //
//===========================================================================//
int MS1553_Send (uint8_t tda, uint8_t sub, uint8_t nWords, void *pData)
{
	int i;
	uint32_t aData[32];
	MIL_STD_1553_CommandWordTypeDef command;

	assert_param( tda < 32 );
	assert_param( sub < 32 );
	assert_param( nWords <= 32 );

	command.CommandWord                  = 0;
	command.Fields.ReadWriteBit          = MIL_STD_1553_BC_TO_TD;
	command.Fields.Data                  = nWords & 0x1F;
	command.Fields.Subaddress            = sub & 0x1F;
	command.Fields.TerminalDeviceAddress = tda & 0x1F;

	MDR_MIL_STD_15531->CommandWord1 = command.CommandWord;

	for( i = 0; i < nWords; i++ )
	{
		aData[i] = ((uint16_t *)pData)[i];
	}
	
	MIL_STD_1553_WiteDataToSendBuffer (MDR_MIL_STD_15531, sub, nWords, aData);
	MIL_STD_1553_StartTransmision (MDR_MIL_STD_15531);
	return SUCCESS;
}

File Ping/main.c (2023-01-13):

/*---------------------------------------------------------------------------*
 * Project:  Ethernet Ping-Pong input/output demonstration firmware.         *
 * Info:     IP Address: 192.168.8.19/255.255.255.0 MAC: see tcpip.h         *
 *           ping 192.168.8.19          arp -a                               *
 * Platform: Milandr 1986VE1T (plasic QFP-144)                               *
 * Note:     tcpip.c uses TIMER1, Max stable F: 96 MHz/Lat:4 (128 MHz/Lat:7) *
 * Version:  0.1 Aug 2020, 0.2 June 2022 (tested ping+, telnet +\-, IRQ)     *
 * Author:   MKM                                                             *
 *---------------------------------------------------------------------------*/
#include <stdint.h>
#include <MDR32F9Qx_port.h>
#include <MDR32F9Qx_rst_clk.h>
#include <MDR32F9Qx_timer.h>
#include <MDR32F9Qx_rst_clk.h>
#include <MDR32F9Qx_eeprom.h>
#include <MDR32F9Qx_eth.h>
#include "tcpip.h"

// PortB
#define MDB_LED_BLUE                   PORT_Pin_2
#define MDB_LED_GREEN                  PORT_Pin_3
#define MDB_LED_RED                    PORT_Pin_4
#define MDB_LED_YELLOW                 PORT_Pin_5
#define MDB_LED_WHITE                  PORT_Pin_6

// PortE
#define MDB_ETH_LED1                   PORT_Pin_9
#define MDB_ETH_LED2                   PORT_Pin_10

// 1ms time counter, extern 
static uint32_t g_msTickCount;
static uint32_t InputFrame[1514/4];

static void LED_Init (void);
static void SYSCLK_Init (void);
static void TIMER2_Init (void);
static void Ethernet_Init (void);

extern void DoNetworkStuff(MDR_ETHERNET_TypeDef*);

//===========================================================================//
//  M A I N                                                                  //
//===========================================================================//
int main()
{
	LED_Init();
	SYSCLK_Init();
	TIMER2_Init();
	Ethernet_Init();

	while(1)
	{
		// Led blinking: Led1 - RX (irq), Led2 - TX (timer).
		if( (g_msTickCount >> 9) & 1 ) // ~0.5 sec
		{
			PORT_ResetBits (MDR_PORTE, MDB_ETH_LED1);
			PORT_ResetBits (MDR_PORTE, MDB_ETH_LED2);
		}
		else
		{
			PORT_SetBits (MDR_PORTE, MDB_ETH_LED2);
		}

		// Send ARP & TCP frames.
		DoNetworkStuff(MDR_ETHERNET1);
	}
}

//===========================================================================//
// Configure PORTB pins for LED on/off                                       //
//===========================================================================//
void LED_Init ( void )
{
	PORT_InitTypeDef PORT_InitStruct;

	PORT_StructInit (&PORT_InitStruct);
	RST_CLK_PCLKcmd (RST_CLK_PCLK_PORTB, ENABLE);
	RST_CLK_PCLKcmd (RST_CLK_PCLK_PORTE, ENABLE);

	PORT_InitStruct.PORT_FUNC  = PORT_FUNC_PORT;
	PORT_InitStruct.PORT_OE    = PORT_OE_OUT;
	PORT_InitStruct.PORT_MODE  = PORT_MODE_DIGITAL;
	PORT_InitStruct.PORT_SPEED = PORT_SPEED_FAST;

	PORT_InitStruct.PORT_Pin   = MDB_LED_BLUE | MDB_LED_GREEN |
	                             MDB_LED_YELLOW | MDB_LED_RED;
	PORT_Init (MDR_PORTB, &PORT_InitStruct);

	PORT_InitStruct.PORT_Pin   = MDB_ETH_LED1 | MDB_ETH_LED2;
	PORT_Init (MDR_PORTE, &PORT_InitStruct);
}

//===========================================================================//
// 80 MHz, HSEdiv1, PLLmul5                                                  //
//===========================================================================//
void SYSCLK_Init ( void )
{
	// Configure FLASH access time for speed >120MHz
	RST_CLK_PCLKcmd (RST_CLK_PCLK_EEPROM, ENABLE);
	EEPROM_SetLatency (EEPROM_Latency_3);
	//EEPROM_SetLatency (EEPROM_Latency_4);
	//--------------------------------//
	// MCU Frequency | Flash Latency  //
	//---------------|----------------//
	//   <  25 MHz   |    0           //
	//   <  50 MHz   |    1           //
	//   <  75 MHz   |    2           //
	//   < 100 MHz   |    3           //
	//   < 125 MHz   |    4 (default) //
	//   < 150 MHz   |    5           //
	//   < 175 MHz   |    6           //
	//--------------------------------//

	// HSE on
	RST_CLK_HSEconfig (RST_CLK_HSE_ON);
	while( RST_CLK_HSEstatus() != SUCCESS ) ;

	// CPU_C1_SEL = HSE, 16 x 5 = 80MHz
	RST_CLK_CPU_PLLconfig ( RST_CLK_CPU_PLLsrcHSEdiv1, RST_CLK_CPU_PLLmul5 ); // 80MHz
	RST_CLK_CPU_PLLcmd (ENABLE);
	while( RST_CLK_CPU_PLLstatus() != SUCCESS ) ;

	// CPU_C2_SEL = PLL
	RST_CLK_CPU_PLLuse (ENABLE);
	// CPU_C3_SEL = CPU_C2_SEL
	RST_CLK_CPUclkPrescaler (RST_CLK_CPUclkDIV1);
	// HCLK_SEL = CPU_C3_SEL
	RST_CLK_CPUclkSelection (RST_CLK_CPUclkCPU_C3);
}

//===========================================================================//
// Timer #2 @ 1000us (1ms)                                                   //
//===========================================================================//
void TIMER2_Init (void)
{
	TIMER_CntInitTypeDef timer = { 0 };
	RST_CLK_FreqTypeDef  freq  = { 0 };

	RST_CLK_PCLKcmd (RST_CLK_PCLK_TIMER2, ENABLE);

	TIMER_DeInit (MDR_TIMER2);
	TIMER_CntStructInit (&timer);
	TIMER_BRGInit (MDR_TIMER2, TIMER_HCLKdiv4);
	RST_CLK_GetClocksFreq (&freq);

	timer.TIMER_CounterMode = TIMER_CntMode_ClkFixedDir;
	timer.TIMER_Period      = freq.CPU_CLK_Frequency/1000000/4 * 1000; // 1000us
	TIMER_CntInit (MDR_TIMER2, &timer);
	TIMER_ITConfig (MDR_TIMER2, TIMER_STATUS_CNT_ARR, ENABLE);

	NVIC_ClearPendingIRQ(TIMER2_IRQn);
	NVIC_EnableIRQ(TIMER2_IRQn);
	TIMER_Cmd(MDR_TIMER2, ENABLE);
}

//===========================================================================//
void TIMER2_IRQHandler(void)
{
	TIMER_ClearITPendingBit (MDR_TIMER2, TIMER_STATUS_CNT_ARR);
	g_msTickCount++;
}
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

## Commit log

2019-07-04 Initial release
    [MDB1986.brd, MDB1986.sch]
2019-12-26 Add files via upload
    Led blinking & JTAG IDCode reader for custom ST-Link.
2019-12-26 Milandr Development Board 1986 Schematics
2019-12-26 Gerber files ready for production (tested).
2019-12-29 MDB1986 Development Board
2020-08-31 This hardware was assembled and tested.
    [M1553io.brd, M1553io.sch]

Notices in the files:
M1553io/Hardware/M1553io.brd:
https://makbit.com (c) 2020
